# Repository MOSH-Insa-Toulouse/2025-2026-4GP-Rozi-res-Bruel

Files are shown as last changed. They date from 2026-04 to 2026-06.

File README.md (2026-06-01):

# 2025-2026-4CP - Projet de capteur low-tech en graphite - Marilou Rozières & Adélaïs Bruel 

## SOMMAIRE
*** 
  - [I. Contexte et description du projet](#contexte-et-description-du)
  - [II. Livrables](#livrables)
  - [III. Matériel nécessaire](#matériel-nécessaire)
  - [IV. Conditionnement analogique](#conditionnement-analogique)
  - [V. Modélisaiotn et simulation](#modélisaiton-et-simulation)
  - [VI. Conception](#conception)
  - [VII. Fabrication](#fabrication)
  - [VIII. Développement firmware et software](#développement-firmware-et-software)
  - [IX. Analyse et caractérisation](#analyse-et-caractérisation)
  - [X. Datasheet](#datasheet)
  - [XI. Conclusion](#conclusion)

*** 

## Contexte et description du projet 

&nbsp;&nbsp;&nbsp;&nbsp;&nbsp;&nbsp;Ce projet s'inscrit dans le cadre de l'UF "Du capteur au banc de test" de la 4ème année Génie Physique de l'INSA Toulouse. 
L'objectif de ce projet est de concevoir, modéliser, prototyper, caractériser et analyser un capteur de déformation low-tech.

&nbsp;&nbsp;&nbsp;&nbsp;&nbsp;&nbsp;Le principe de fonctionnement du capteur repose sur la piézorésistivité d'un dépôt de graphite (réalisé à l'aide d'un simple crayon de bois) sur un support flexible (une feuille de papier). 
Microscopiquement, le trait de crayon est un agglomérat de feuillets de graphite. Dans ce milieu granulaire complexe, la conduction se fait principalement par effet tunnel : les nombreux grains sont séparés par de très fins interstices, la probabilité de passage des électrons d'un grain de graphite à l'autre par franchissement de l'interstice est non nulle si cette barrière est suffisament fine. Cette probabilité dépend exponentiellement de la distance *d* qui sépare les deux grains.
Ce paramètre physique est alors à l'origine de la variation de résistance : en tension, l'écart *d* entre les particules augmente, la probabilité de passage est plus faible, la résistance globale du capteur augmente. 
Tandis qu'en compression, la distance *d* diminue, les particules se rapprochent, la probabilité d'échange augmente, la résistance chute. 
La dépendance exponentielle de la résistance à la distance *d* explique pourquoi une très faible variation du capteur va nous permettre de lire des varirations de signal (résistance) importantes. 

&nbsp;&nbsp;&nbsp;&nbsp;&nbsp;Pour passer d'un trait de crayon à un capteur fonctionnel, le projet s'est déroulé selon ces différentes phases :
- **Conditionnement analogique** : Conception d'un amplificateur transimpédance (conversion courant-tension) pour transformer les variations de courant (de l'ordre du nA) en un signal de tension exploitable (0−5V).
- **Modélisation et Simulation** : Utilisation de LTSpice pour dimensionner les filtres actifs et passifs afin d'éliminer le bruit parasite (notamment le 50 Hz du secteur).
- **Conception** : Routage d'un circuit imprimé (Shield PCB) sous KiCad pour intégrer l'électronique, l'écran OLED et le module Bluetooth.
- **Fabrication** : Réalisation physique du PCB par insolation, gravure chimique (perchlorure de fer), perçage et soudure des composants.
- **Développement Firmware & Software** : Programmation de la carte Arduino (gestion de l'I2C, SPI et UART) et création d'une interface mobile sous MIT App Inventor.
- **Analyse** : Caractérisation du capteur sur un banc de test dédié et rédaction d'une datasheet technique.

Ce document a pour objectif d'expliciter ces différentes étapes.  

## Livrables 
Les livrables attendus sont les suivants : 
- **Un shield PCB connecté à une carte arduino UNO** avec différents composants : un capteur graphite, un amplificateur transimpédance, un module bluetooth, un écran OLED, un flex sensor commercial, un potentiomètre digital, un encodeur rotatoire. D'autres composants peuvent être implémentés ;
- **Un code arduino** qui gère les différents composants cités précédemments (mesures de contraintes, échanges bluetooth et OLED, potentiomètre digital et boutons) ;
- **Une application Android** (sous MIT App Inventor) interfaçant le PCB et le code Arduino correspondant;
- **Une datasheet du capteur** reprenant toutes ses caractéristiques ainsi que ses tests.

## Matériel nécessaire

Afin de réaliser notre dispositif électronique, nous avons eu besoin de :

**Pour le montage amplificateur transimpédance :**

- Résistances : une de 1 kΩ, une de 10 kΩ et deux de 100 kΩ - une troisième de 100 kΩ peut être prévue, mais peut aussi être substituée par une résistance variable (le potentiomètre digital), choix que l'on a fait ;
- Potentiomètre digital MCP41050 et son support ;
- Amplificateur opérationnel LTC1050 et son support ;
- Capacités : trois de 100 nF et une de 1 μF.

**Pour le reste du dispositif :**

- Arduino Uno et son câble d’alimentation ;
- Résistance : une de 47kΩ pour le flex sensor ;
- Module Bluetooth HC05 ;
- Ecran OLED de dimension 128*64 ;
- Flex sensor ;
- Encodeur rotatoire ;
- Capteur graphite et 2 pinces crocodiles ;
- 20 sockets ;
- 35 headers.

## Conditionnement analogique 

&nbsp;&nbsp;&nbsp;&nbsp;&nbsp;Le capteur en graphite présente une résistance extrêmement élevée (de l'ordre du MΩ), ce qui génère des courants infimes (pico- à nanoampères) sous une tension de 5 V. Pour transformer ce signal en une tension exploitable par l’ADC d'une Arduino UNO (0−5V), nous avons conçu un amplificateur transimpédance, réalisé comme suit : 

Capture d’écran 2026-03-27 à 16 34 57

Nous avons utilisé l’AOP LTC1050 car il possède un courant de biais d'entrée extrêmement faible et un offset quasi nul, évitant ainsi de fausser les mesures de courants très faibles. 
Nous avons placé une résistance de protection (R5) en entrée pour protéger l'AOP contre les décharges électrostatiques, ainsi qu'une résistance du shunt (R1) qui assure la référence à la masse. La résistance de rétroaction (R2) a été subsitué par un potentiomètre digital MCP41050 pour ajuster dynamiquement le gain du montage via le code Arduino. 
Les trois étages de filtrages de cet amplificateur permet de minimiser au maximum les bruits parasites. 

## Modélisation et simulation 

&nbsp;&nbsp;&nbsp;&nbsp;&nbsp;Avant la fabrication, l'ensemble du circuit a été modélisé sous LTSpice pour vérifier que l'amplification convertit bien les nanoampères en une tension comprise entre 0 et 5V. Cette modélisation a également permis de valider l'efficacité de nos trois étage de filtrage :  
- Filtre passe-bas (16 Hz) : élimination des hautes fréquences parasites.
- Filtre passe-bas (1,6 Hz) : atténuation drastique du bruit secteur (50 Hz)
- Filtre passe-bas (1,6 kHz) : supression des interférences liées à la communication de l'ADC.

Schema du montage transimpedance

## Conception 
&nbsp;&nbsp;&nbsp;&nbsp;&nbsp;La phase de conception a été réalisée sur Kicad. L'ojectif était de créer un Shield compatible avec le format de l'Arduino UNO. 
Cela nous demandé trois étapes : 
- Saisie des empreintes et des shématics associés pour nos différents composants : AOP, potentiomètre digital, écran OLED, encodeur rotatoire et module bluetooth. 
- Le routage du PCB : optimisation du placement des composants pour réduire les longueurs de pistes et visualisation 3D des composants pour vérifier l'abscence de conflits mécaniques entre tous les composants.
- Ajout d'un plan de masse pour minimiser le bruit électromagnétique et stabiliser les mesures de hautes impédances.
pcb sch

## Fabrication 
&nbsp;&nbsp;&nbsp;&nbsp;&nbsp;La réalisation du prototype a été faite par ce processus de fabrication : 
- Insolation & gravure (réalisé par Catherine Crouzet) : transfert du masque de gravure sur une plaque époxy et passage au perchlorure de fer.
- Nettoyage (réalisé par Catherine Crouzet) : Retrait de la résine photosensible à l'acétone pour révéler les pistes de cuivre.
- Percage & soudure : montage manuel des composants sur le PCB final.
- Assemblage : soudure des composants.



## Développement Firmaware et Software 

Le système est piloté par deux pôles : 
- Firmware (Arduino) : utilisation des bibliothèques *Adafruit_SSD1306* (OLED), *SPI* (potentiomètre) et *SoftwareSerial* (Bluetooth). Le code génère un menu intéractif via l'encodeur rotatoire pour calibrer le capteur et lancer les mesures.
- Interface mobile : développement d'une application Android sur MIT App Inventor qui communique en Bluetooth pour afficher la résistance en temps réel et tracer la courbe de déformation directement sur le smartphone.




## Analyse et caractérisation

**Dispositif de mesure :** 

&nbsp;&nbsp;&nbsp;&nbsp;&nbsp;Afin d’obtenir les caractéristiques spécifiques du capteur, nous avons utilisé un banc de test composé de six cylindres de diamètre différent, permettant d’étudier la résistance de notre capteur en tension et en compression pour six valeurs de contraintes connues.  
sch

&nbsp;&nbsp;&nbsp;&nbsp;&nbsp;Nous avons choisi d’étudier trois types de crayons à papier différent : le B, le 3B et le 6B. Nous avons donc conçu trois capteurs différents, et avons déterminé pour chacun d’entre eux douze valeurs : six en compression et six en tension. Ces mesures nous ont permises d’établir la variation relative de résistance en fonction de la déformation grâce aux formules suivantes : 

Calcul de la déformation ∶ ε=  e/D

Avec e l’épaisseur du papier utilisé pour le capteur et D le diamètre du cylindre sur lequel est effectué la mesure. 

Calcul de la variation relative de résistance∶ ∆R/R0 (%)=  (R_mesuré-R0)/R0

**Résultats des mesures :**

En tension, nous obtenons alors la variation relative de résistance en fonction de la déformation suivante : 
sch

En compression, nous obtenons la variation relative de la résistance en fonction de la déformation suivante : 

sch

&nbsp;&nbsp;&nbsp;&nbsp;&nbsp;Les allures des courbes sont pertinentes : les crayons à papier sont constitués de graphite et d’un liant isolant (argile). Afin de comprendre la différence entre les différents types de crayons (B, 3B, 6B, …) il faut se pencher sur le seuil de percolation de ceux-ci. Le seuil de percolation représente la fraction volumique nécessaire de charge conductrice (ici le graphite) afin que celles-ci forment un réseau continu interconnecté à travers la matrice isolante (l’argile). A partir de ce seuil de matière conductrice, les propriétés macroscopiques du matériau basculent d’un comportement isolant à un comportement conducteur. Un crayon 6B est saturé en graphite et contient très peu d’argile (seuil de percolation largement dépassé), il représente alors un milieu très conducteur. Quand une déformation est appliquée au capteur, des micro fissures sont créées, mais il existe une multitude de chemins secondaires conducteurs, la résistance globale du capteur n’est que très peu impactée. A contrario, le crayon B a une mine dure, il contient une forte proportion d’argile (très proche du seuil de percolation), les grains de graphite sont plus dispersés dans la matrice d’argile isolante, lorsqu’une déformation est appliquée, les rares chemins électriques entre les grains de graphite se brise très facilement, la résistance varie alors fortement. 

**Analyse :**

&nbsp;&nbsp;&nbsp;&nbsp;&nbsp;La sensibilité (facteur de jauge k) est définie par : k=  (∆R/R0)/ε
Le crayon B possède la meilleure sensibilité puisque pour une déformation donnée il génère une plus grande variation de résistance. Diminuer la concentration de charge conductrice (en passant de 6B à B) augmente alors fortement la piézorésistivité du matériau. 
Pour conclure, pour une application requérant une grande sensibilité un capteur réalisé avec un crayon de type B est le mieux, néanmoins celui-ci aura tendance à « s’user » plus vite puisque que sa composition est au niveau du seuil de percolation. Tandis que pour une application nécessitant moins de précision mais plus de robustesse, un crayon très gras tel que le 6B conviendra mieux, puisque qu’étant très loin du seuil de percolation il peut être déformé plus de fois avant de ne plus avoir chemins conducteurs possible entre les particules.  

## Datasheet
La datasheet du capteur est disponible [ici](https://github.com/MOSH-Insa-Toulouse/2025-2026-4GP-Rozi-res-Bruel/blob/main/DATASHEET/DATASHEET.pdf)

## Conclusion 
&nbsp;&nbsp;&nbsp;&nbsp;&nbsp;Pour conclure ce projet, ce capteur low tech est adapté non pas à la lecture d’une valeur de résistance et donc de déformation mais plutôt à la détection d’un mouvement. Il serait également intéressant dans une application jetable puisque qu’au bout de 5/10 utilisations il n’est plus fonctionnel.

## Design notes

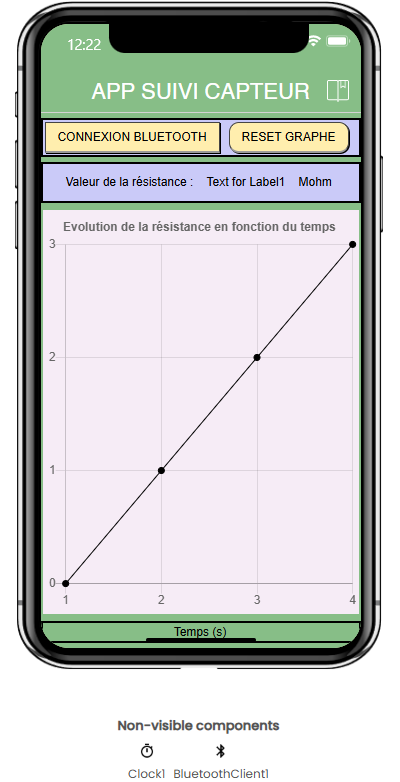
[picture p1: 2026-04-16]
APPLICATION_ANDROID/face_avant_app.png

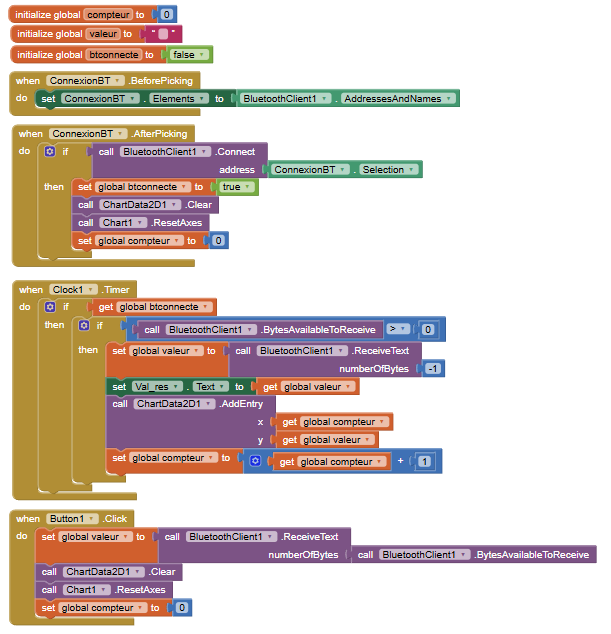
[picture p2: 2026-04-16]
APPLICATION_ANDROID/face_arriere_app.png

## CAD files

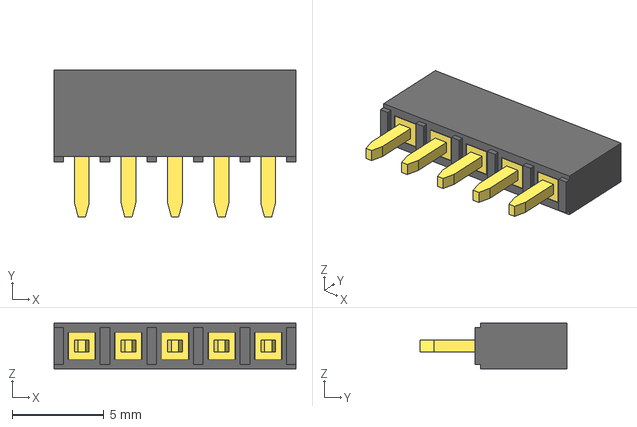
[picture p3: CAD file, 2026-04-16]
KICAD/Models 3D/5-Pin Header - Female - 2.54mm.step
13.2 x 8.00 x 2.50 mm

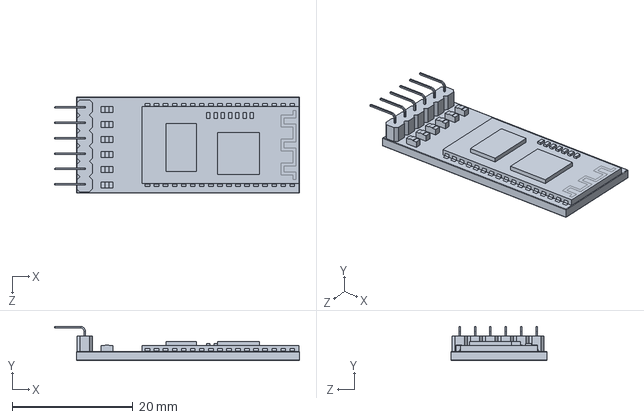
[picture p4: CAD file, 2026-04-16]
KICAD/Models 3D/HC05_BLUETOOTH.STEP
40.6 x 5.67 x 16.0 mm

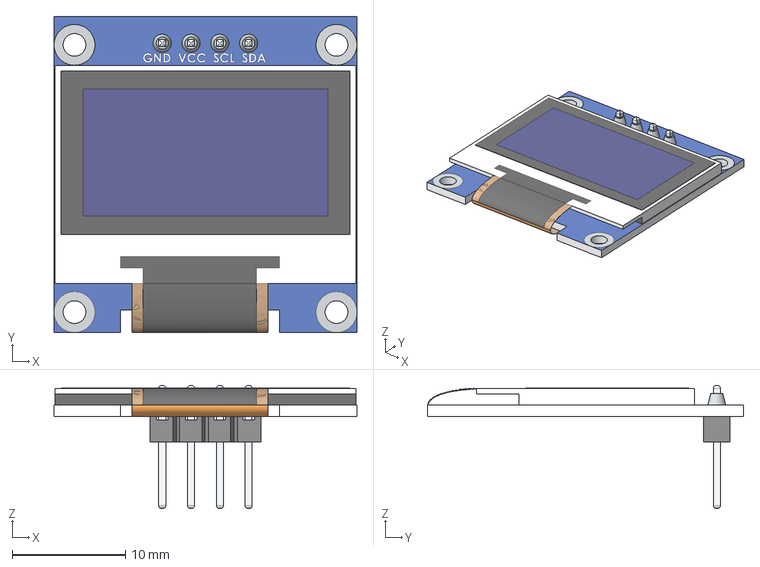
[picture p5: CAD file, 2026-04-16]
KICAD/Models 3D/OLED-128x64-0.96.step
26.7 x 27.9 x 10.8 mm

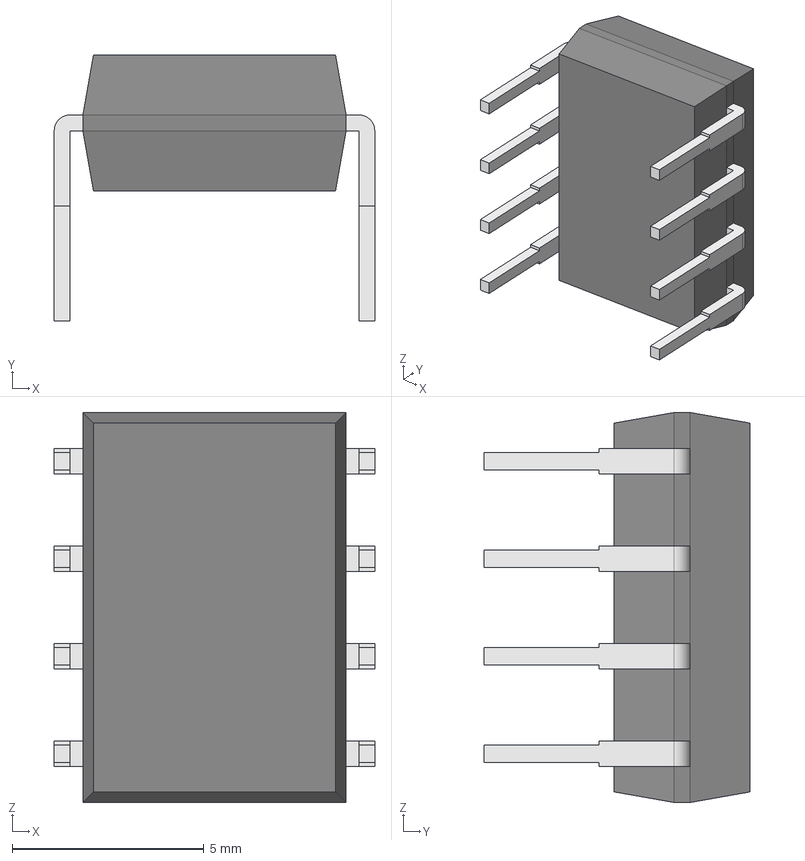
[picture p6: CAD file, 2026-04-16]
KICAD/Models 3D/LTC1050CN8_PBF.step
8.35 x 6.93 x 10.2 mm
Body001 (Mirror #1) x 5

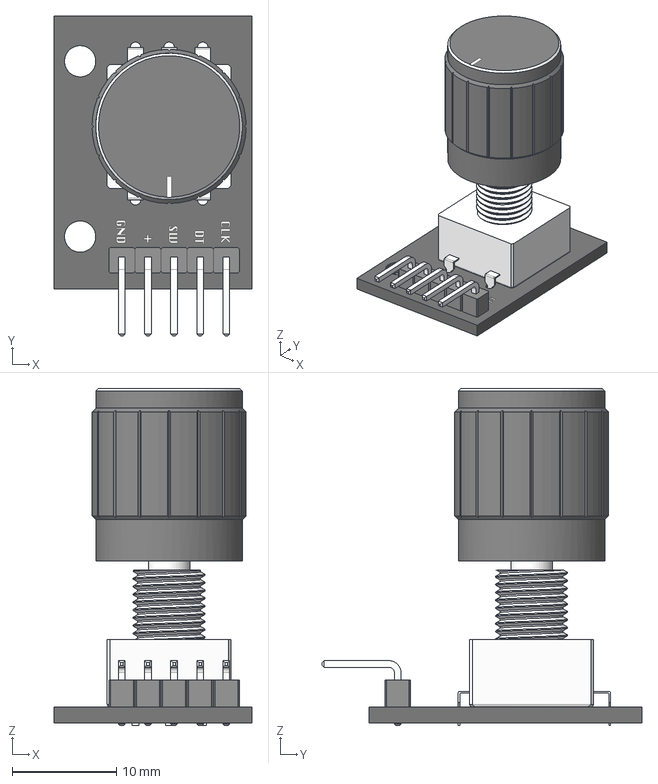
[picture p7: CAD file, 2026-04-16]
KICAD/Models 3D/Rotary Encoder - KY-040.step
19.0 x 30.8 x 32.4 mm

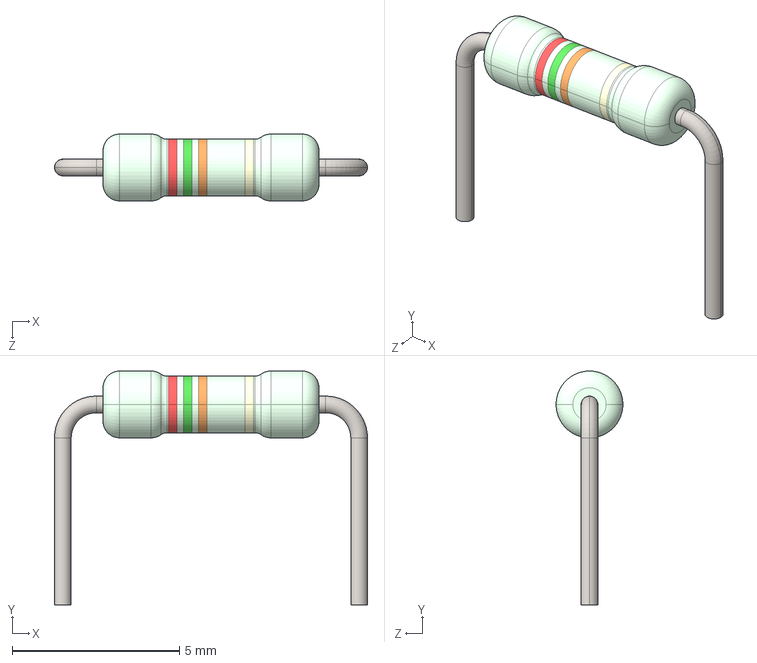
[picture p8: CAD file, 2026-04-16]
KICAD/Models 3D/Resistor.STEP
9.36 x 7.00 x 2.00 mm

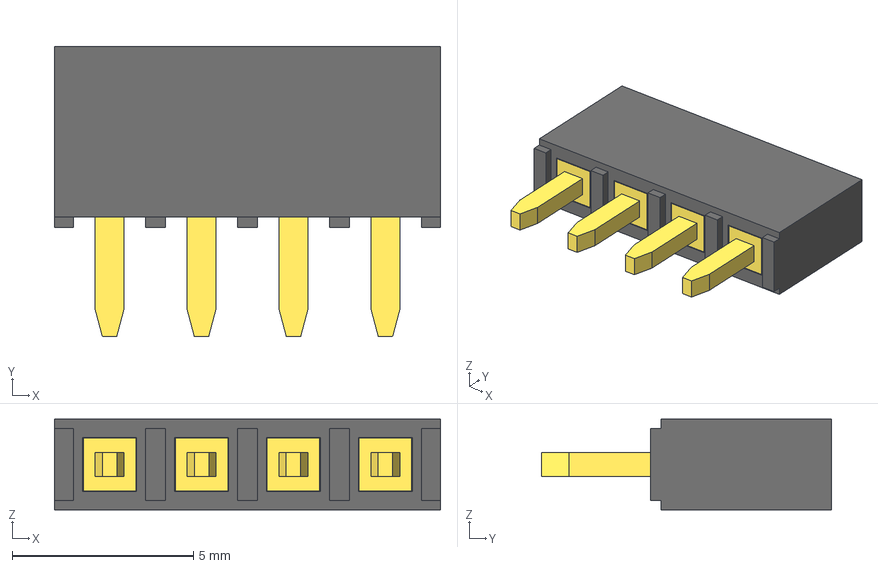
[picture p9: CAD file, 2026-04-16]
KICAD/Models 3D/4-Pin Header - Female - 2.54mm.step
10.7 x 8.00 x 2.50 mm

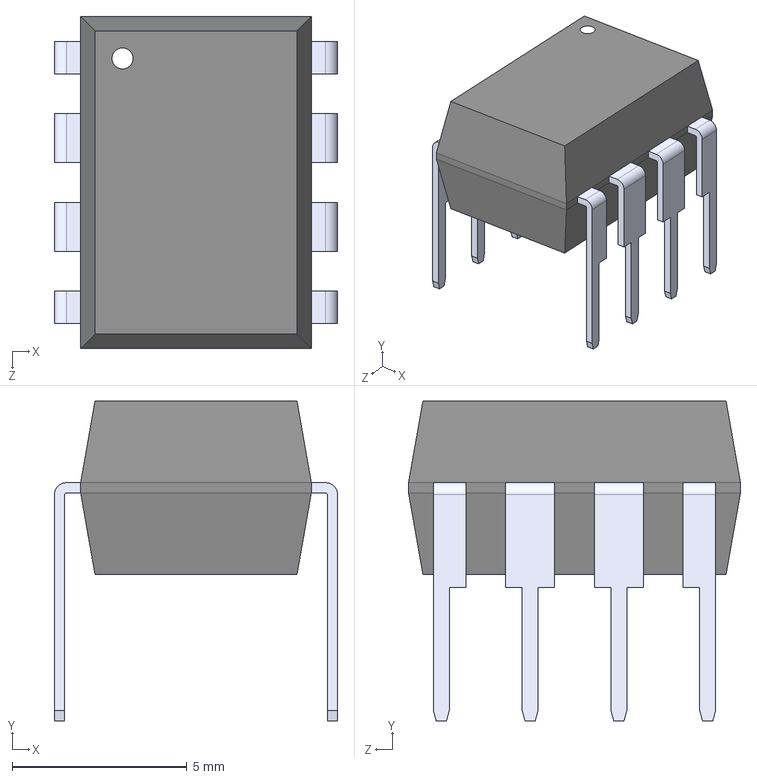
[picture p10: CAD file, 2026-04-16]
KICAD/Models 3D/MCP41010-E_P.step
8.10 x 9.14 x 9.50 mm

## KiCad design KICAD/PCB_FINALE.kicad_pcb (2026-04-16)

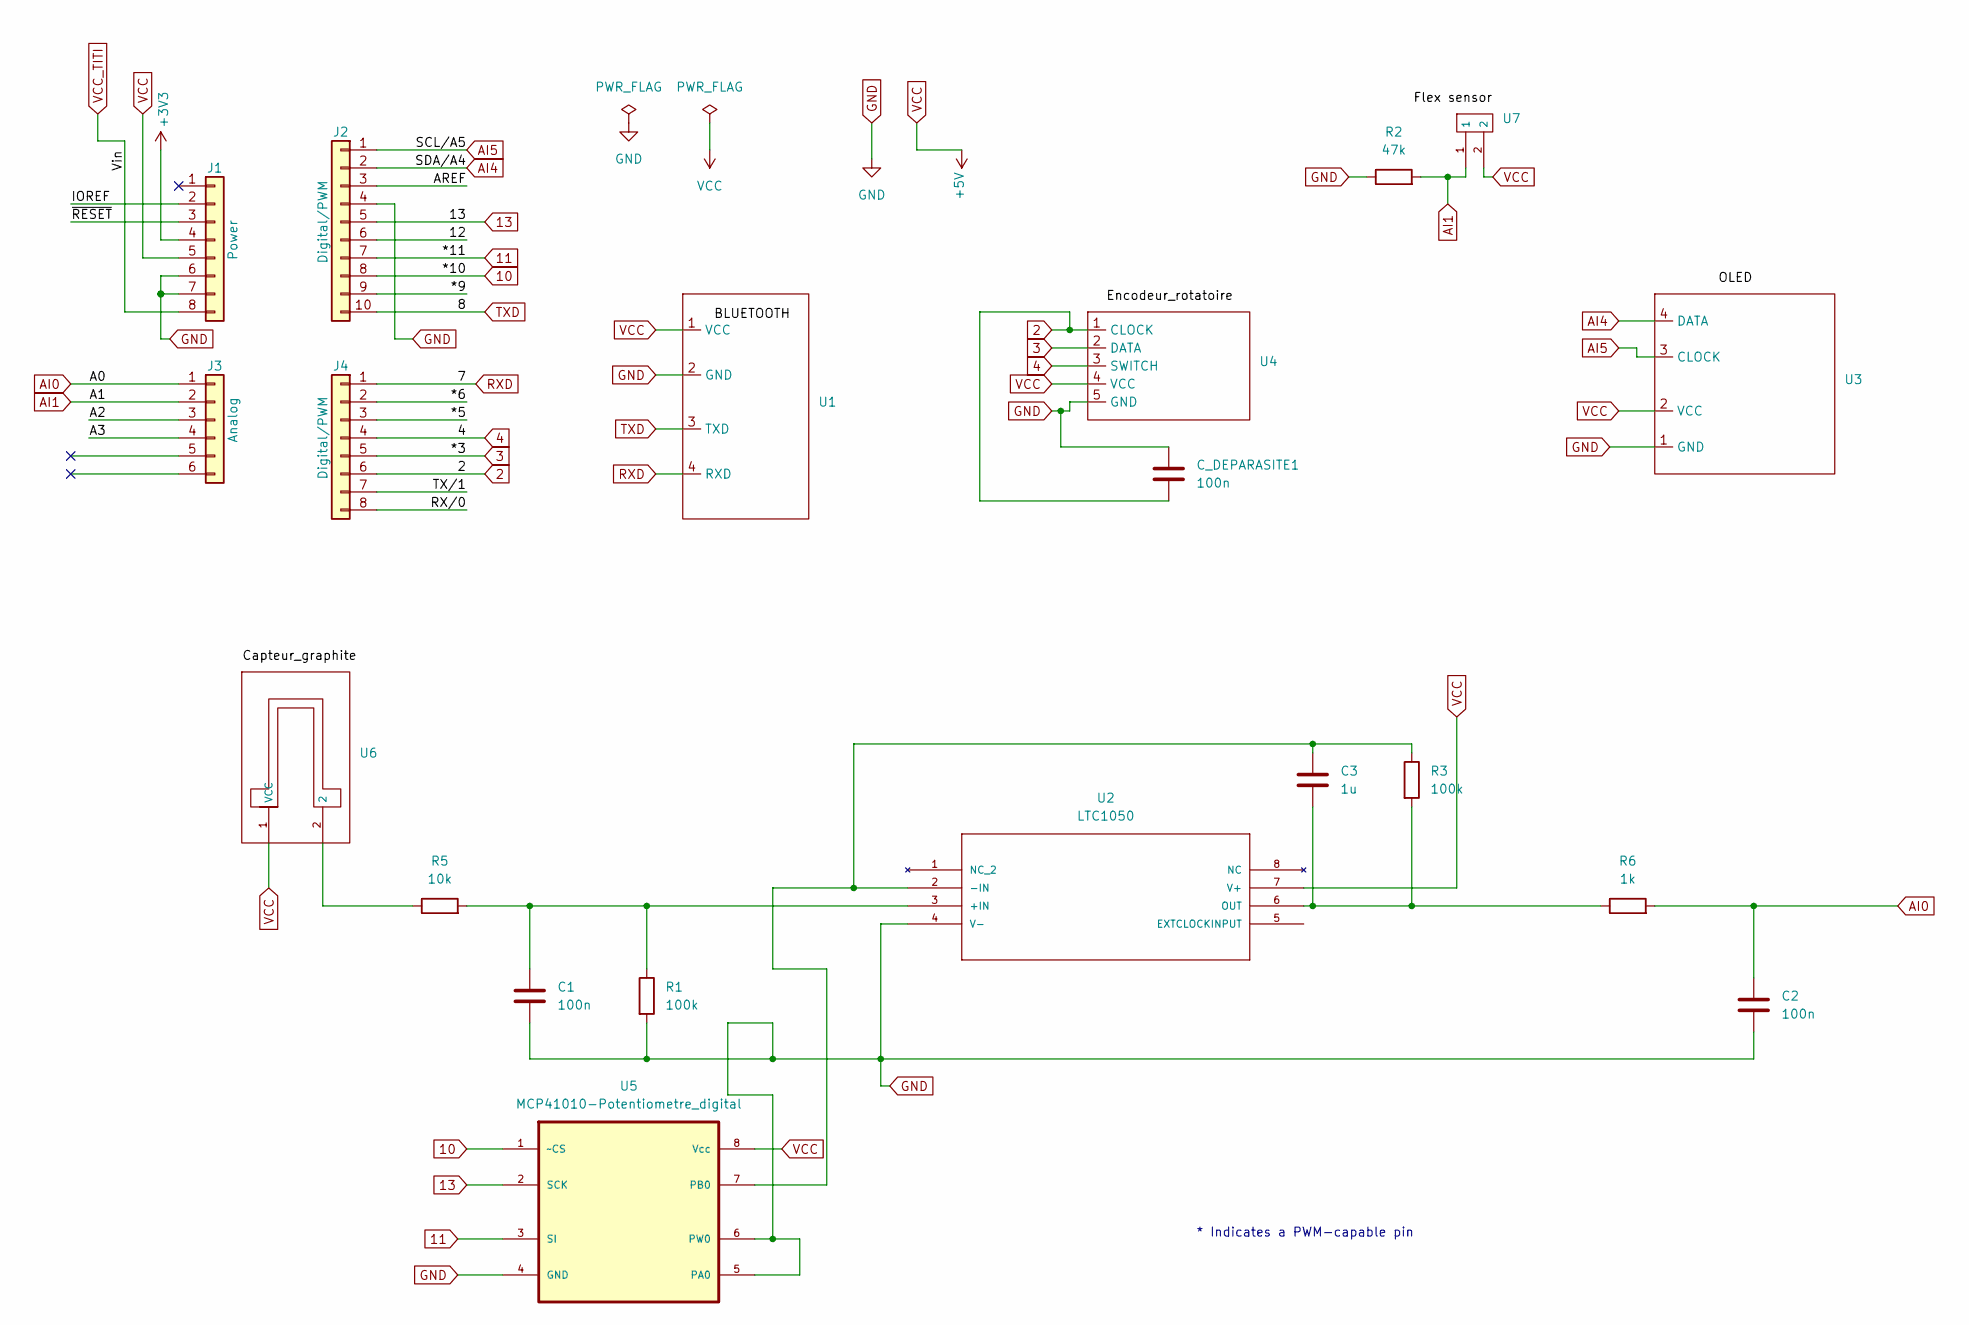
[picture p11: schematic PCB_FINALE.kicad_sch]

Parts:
C1, C2: 100n; CapaOk
C3: 1u; CapaOk
C_DEPARASITE1: 100n; CapaOk
J1: Power; PinSocket_1x08_P2.54mm_Vertical
J2: Digital/PWM; PinSocket_1x10_P2.54mm_Vertical
J3: Analog; PinSocket_1x06_P2.54mm_Vertical
J4: Digital/PWM; PinSocket_1x08_P2.54mm_Vertical
R1, R3: 100k; RES5
R2: 47k; RES5
R5: 10k; RES5
R6: 1k; RES5
U1: Bluetouth_HC05
U2: LTC1050; PDIP-8_N; MANUFACTURER_PART_NUMBER ltc1050cn8
U3: OLED_EMPREINTE
U4: ENCODEUR_ROTATOIRE
U5: MCP41010-Potentiometre_digital; Potentiomètre_digital
U6: capteur_graphite
U7: FLEX_SENSOR

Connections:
2: C_DEPARASITE1.2, J4.6, U4.1 (CLOCK)
3: J4.5, U4.2 (DATA)
4: J4.4, U4.3 (SWITCH)
10: J2.8, U5.1 (~CS)
11: J2.7, U5.3 (SI)
13: J2.5, U5.2 (SCK)
+3V3: J1.4
/12: J2.6
/*5: J4.3
/*6: J4.2
/*9: J2.9
/A2: J3.3
/A3: J3.4
/AREF: J2.3
/IOREF: J1.2
/RX/0: J4.8
/TX/1: J4.7
/~RESET: J1.3
AI0: C2.1, J3.1, R6.2
AI1: J3.2, R2.2, U7.1
AI4: J2.2, U3.4 (DATA)
AI5: J2.1, U3.3 (CLOCK)
GND: C1.2, C2.2, C_DEPARASITE1.1, J1.6, J1.7, J2.4, R1.2, R2.1, U1.2 (GND), U2.4 (V-), U3.1 (GND), U4.5 (GND), U5.4 (GND), U5.5 (PA0), U5.6 (PW0)
unnamed: R5.1, U6.2
unnamed: C1.1, R1.1, R5.2, U2.3 (+IN)
unnamed: C3.1, R3.1, U2.2 (-IN), U5.7 (PB0)
unnamed: C3.2, R3.2, R6.1, U2.6 (OUT)
RXD: J4.1, U1.4 (RXD)
TXD: J2.10, U1.3 (TXD)
VCC: J1.5, U1.1 (VCC), U2.7 (V+), U3.2 (VCC), U4.4 (VCC), U5.8 (Vcc), U6.1 (VCC), U7.2
VCC_TITI: J1.8

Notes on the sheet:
* Indicates a PWM-capable pin

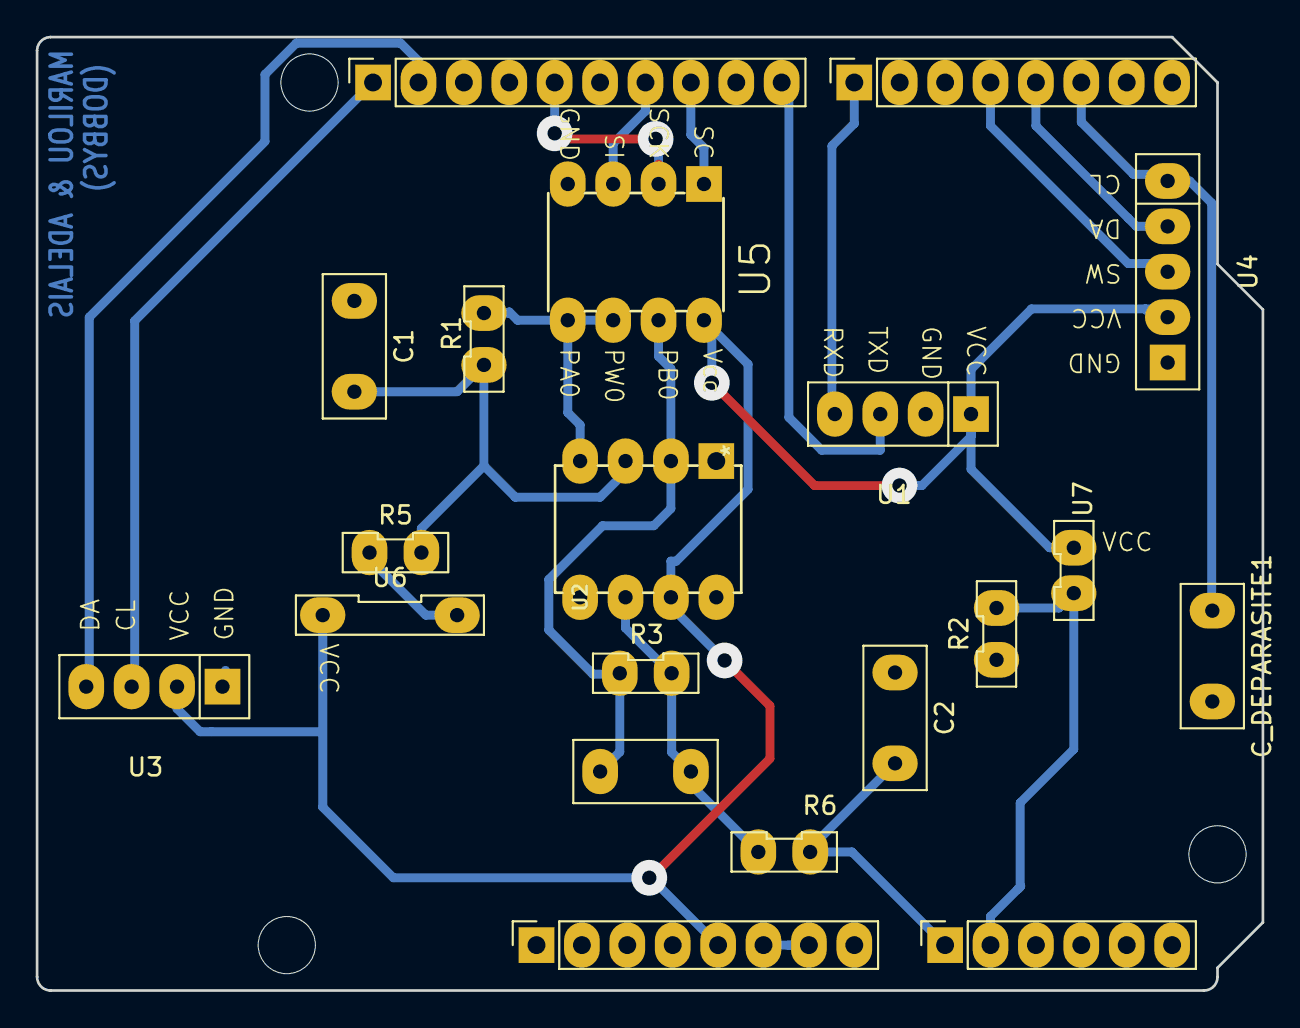
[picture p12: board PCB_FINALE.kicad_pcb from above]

Board: 2 copper layers, 68.6 x 53.3 mm, 23 parts (0 on the bottom side), 18 nets.

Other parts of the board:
MH1, MH2, MH4: MountingHole_3.2mm

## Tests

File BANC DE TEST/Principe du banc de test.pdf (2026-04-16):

### Banc de test et résultats

I – Dispositif de mesure
II – Résultats des mesures III – Conclusion

## I – Dispositif de mesure

Afin d’obtenir les caractéristiques spécifiques du capteur, nous avons utilisé un banc de test composé de six cylindres de diamètre différent, permettant d’étudier la résistance de notre capteur en tension et en compression pour six valeurs de contraintes connues.

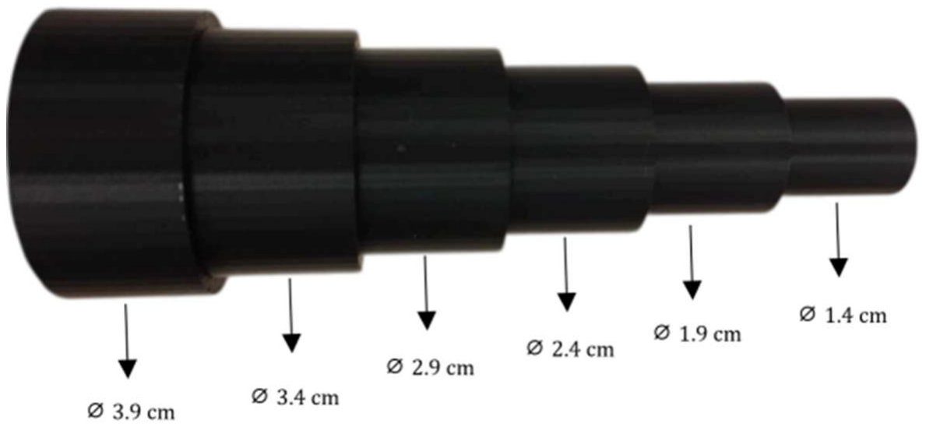
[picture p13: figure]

Figure 1 : Banc de test imprimé en 3D
Nous avons choisi d’étudier trios types de crayons à papier différent : le B, le 3B et le 6B. Nous avons donc conçu trois capteurs différents, et avons déterminé pour chacun d’entre eux douze valeurs : six en compression et six en tension. Ces mesures nous ont permises d’établir la variation relative de résistance en fonction de la déformation grâce aux formules suivantes :
o Calcul de la déformation ∶ | ε =

Avec e l’épaisseur du papier utilisé pour le capteur et D le diamètre du cylindre sur lequel est effectué la mesure.

o Calcul de la variation relative de résistance ∶

∆R
R0
| (%) = Ré − R0
R0

## II – Résultats des mesures

Nous avons organisé nos résultats dans les tableaux suivants :

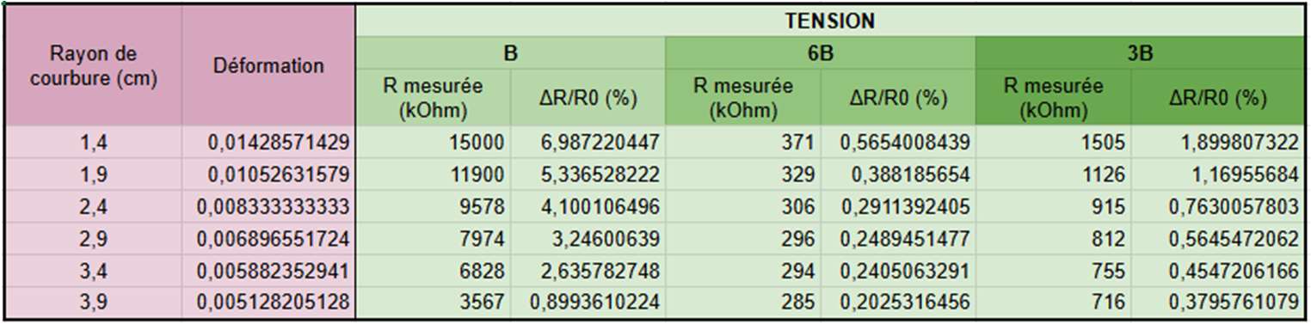
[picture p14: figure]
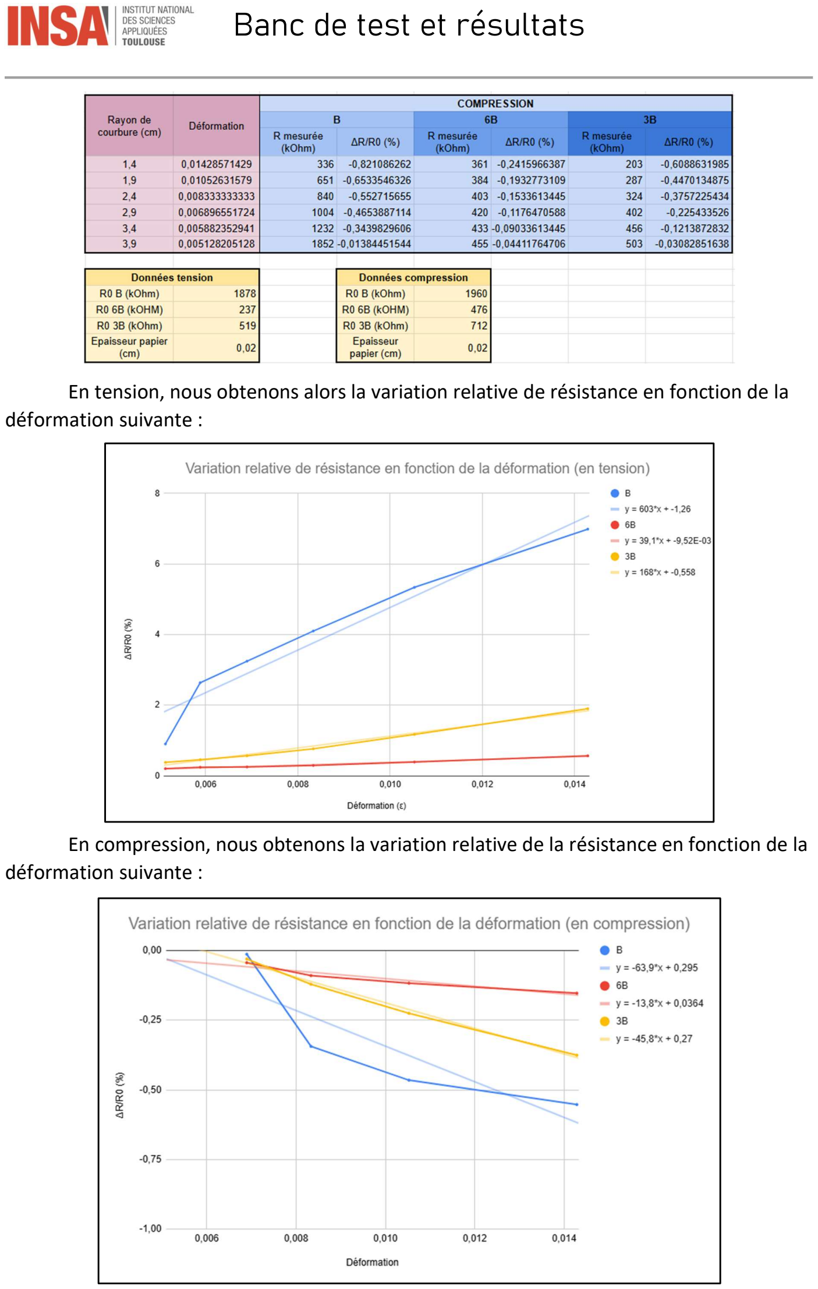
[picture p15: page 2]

En tension, nous obtenons alors la variation relative de résistance en fonction de la déformation suivante :

En compression, nous obtenons la variation relative de la résistance en fonction de la déformation suivante :

Les allures des courbes sont pertinentes : les crayons à papier sont constitués de graphite et d’un liant isolant (argile). Afin de comprendre la différence entre les différents types de crayons (B, 3B, 6B, …) il faut se pencher sur le seuil de percolation de ceux-ci. Le seuil de percolation représente la fraction volumique nécessaire de charge conductrice (ici le graphite) afin que celles-ci forment un réseau continu interconnecté à travers la matrice isolante (l’argile). A partir de ce seuil de matière conductrice, les propriétés macroscopiques du matériau basculent d’un comportement isolant à un comportement conducteur. Un crayon 6B est saturé en graphite et contient très peu d’argile (seuil de percolation largement dépassé), il représente alors un milieu très conducteur. Quand une déformation est appliquée au capteur, des micro fissures sont créées, mais il existe une multitude de chemins secondaires conducteurs, la résistance globale du capteur n’est que très peu impactée. A contrario, le crayon B a une mine dure, il contient une forte proportion d’argile (très proche du seuil de percolation), les grains de graphite sont plus dispersés dans la matrice d’argile isolante, lorsqu’une déformation est appliquée, les rares chemins électriques entre les grains de graphite se brise très facilement, la résistance varie alors fortement.

## III – Conclusion

La sensibilité (facteur de jauge k) est définie par :

k =

∆R/R0
ε
Le crayon B possède la meilleure sensibilité puisque pour une déformation donnée il génère une plus grande variation de résistance. Diminuer la concentration de charge conductrice (en passant de 6B à B) augmente alors fortement la piézorésistivité du matériau.
Pour conclure, pour une application requérant une grande sensibilité un capteur réalisé avec un crayon de type B est le mieux, néanmoins celui-ci aura tendance à « s’user » plus vite puisque que sa composition est au niveau du seuil de percolation. Tandis que pour une application nécessitant moins de précision mais plus de robustesse, un crayon très gras tel que le 6B conviendra mieux, puisque qu’étant très loin du seuil de percolation il peut être déformé plus de fois avant de ne plus avoir chemins conducteurs possible entre les particules.

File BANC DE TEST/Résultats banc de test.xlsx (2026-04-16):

Diamètre (cm) | Déformation | TENSION
 |  | B |  | 6B |  | 3B |  | FLEX SENSOR
 |  | R mesurée (kOhm) | ΔR/R0 | R mesurée (kOhm) | ΔR/R0 (%) | R mesurée (kOhm) | ΔR/R0 | R mesurée (kOhm) | ΔR/R0
1.4 | 0.01428571429 | 15000 | 6.987220447 | 371 | 0.5654008439 | 1505 | 1.899807322
1.9 | 0.01052631579 | 11900 | 5.336528222 | 329 | 0.388185654 | 1126 | 1.16955684
2.4 | 0.008333333333 | 9578 | 4.100106496 | 306 | 0.2911392405 | 915 | 0.7630057803
2.9 | 0.006896551724 | 7974 | 3.24600639 | 296 | 0.2489451477 | 812 | 0.5645472062 | 78 | 2.545454545
3.4 | 0.005882352941 | 6828 | 2.635782748 | 294 | 0.2405063291 | 755 | 0.4547206166 | 75 | 2.409090909
3.9 | 0.005128205128 | 3567 | 0.8993610224 | 285 | 0.2025316456 | 716 | 0.3795761079 | 68 | 2.090909091
Diamètre (cm) | Déformation | COMPRESSION
 |  | B |  | 6B |  | 3B
 |  | R mesurée (kOhm) | ΔR/R0 | R mesurée (kOhm) | ΔR/R0 | R mesurée (kOhm) | ΔR/R0
1.4 | 0.01428571429 | 129 | -0.9313099042 | 361 | -0.2415966387 | 203 | -0.6088631985
1.9 | 0.01052631579 | 324 | -0.8274760383 | 384 | -0.1932773109 | 287 | -0.4470134875
2.4 | 0.008333333333 | 418 | -0.7774227902 | 403 | -0.1533613445 | 324 | -0.3757225434
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

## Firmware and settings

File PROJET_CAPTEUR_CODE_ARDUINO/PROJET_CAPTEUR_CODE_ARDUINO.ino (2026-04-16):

//BIBLIOTHEQUES

#include <SoftwareSerial.h>  //Bluetooth
#include <Wire.h>   //OLED
#include <Adafruit_SSD1306.h>   //OLED
#include <SPI.h>  //Potentiomètre
#include <stdlib.h>

//DEF & CST
#define baudrate 9600

  //Bluetooth:
#define rxPin 8
#define txPin 7

  //Encodeur rotatoire:
#define Encodclkpin 2 
#define Encoddtpin 3 
#define Encodswpin 4

  //OLED:
#define nombreDePixelsEnLargeur 128 
#define nombreDePixelsEnHauteur 64 
#define brocheResetOLED -1 
#define adresseI2CecranOLED 0x3C
#define nb_item 3 //Nombre de choix dans le menu

  //Potentiomètre digital:
#define MCP_NOP                 0b00000000
#define MCP_WRITE               0b00010001
#define MCP_SHTDWN              0b00100001

  //Flex sensor:
#define flexPin A1

  //Capteur graphite:
#define graphitePin A0

//VARIABLES

  //Bluetooth:
SoftwareSerial mySerial (rxPin, txPin);

  //Encodeur:
volatile int Pas_encod = 0; // variable pour stocker la lecture de l'etat du bouton (crans)
int etat_bouton = 0; // variable pour stocker la lecture de l'etat du bouton (enfoncé)
int Menu = 0;

  //Flex sensor:
float val_flexs = 0;
float Vflexs, Rflexs = 0.0;
const float VCC = 5.0;
const float Rdiv = 47000.0;
const float flatres = 24700.0;
const float bentres = 80000.0;

  //Capteur graphite:
unsigned long previousMillis = 0; //Pour faire une clock
int val_graph = 0;
float VGraph, RGraph = 0.0;
const float R1 = 100000;
const float R3 = 100000;
const float R5 = 10000;

  //OLED:
int choix = 0;
float lastval = -100.0;

  //Potentiomètre digital:
const int csPin = 10;
const int maxPositions = 256;
const long rAB = 47000;
const byte rWiper = 125;
const byte pot0 = 0x11;
const byte pot0shutdown = 0x21;
float R2;

Adafruit_SSD1306 ecranOLED (nombreDePixelsEnLargeur, nombreDePixelsEnHauteur, &Wire, brocheResetOLED);

void setup() { //Configuration et initialisation des différents composants 

  Serial.begin(9600);

  //OLED:
  if (!ecranOLED.begin (SSD1306_SWITCHCAPVCC, adresseI2CecranOLED)) { // Arrêt du programme (boucle infinie) si échec d'initialisation
    while(1);
  }

  //Calibration
  ecranOLED.clearDisplay();
  ecranOLED.setTextSize(1);
  ecranOLED.setTextColor(SSD1306_WHITE);
  ecranOLED.setCursor(0,0);
  ecranOLED.println(F("Calibration en cours..."));
  ecranOLED.println(F("Veuillez ne pas toucher"));
  ecranOLED.println(F("le capteur."));
  ecranOLED.display();

  //Pontentiometre digital :
  pinMode(csPin, OUTPUT);
  digitalWrite(csPin, HIGH);
  SPI.begin();
  Calibration(); 
  ecranOLED.clearDisplay();
  ecranOLED.setCursor(0,0);
  ecranOLED.println(F("Calibration OK !"));
  ecranOLED.display();
  delay(1000);

  //Encodeur rotatoire:
  pinMode(Encodclkpin, INPUT); 
  digitalWrite(Encodclkpin, HIGH); 
  pinMode(Encoddtpin, INPUT); 
  digitalWrite(Encoddtpin, HIGH);
  pinMode(Encodswpin, INPUT); 
  digitalWrite(Encodswpin, HIGH);
  attachInterrupt(0, doEncoder, RISING); // On met une interruption sur l'encodeur

  //Module Bluetooth:
  pinMode (rxPin,INPUT);
  pinMode (txPin,OUTPUT);
  mySerial.begin(baudrate);

  //Capteurs:
  pinMode(flexPin, INPUT);
  pinMode(graphitePin, INPUT);

  delay(500);

}

//LOOP

void loop() {                               // Boucle en continue 

  Afficher_Menu(); //Appelée toutes les 500ms

}

//FONCTIONS

float flexSensor(){                       // Renvoie la valeur de la résistance aux bornes du flex sensor
  float ADCflex = analogRead(flexPin);
  Vflexs = ADCflex * VCC / 1024.0;
  Rflexs = Rdiv * (VCC / Vflexs - 1.0);
  return Rflexs;
}

float graphiteSensor(){                   // Renvoie la valeur de la résisatnce aux bornes du capteur graphite
  float ADCgraph = analogRead(graphitePin); 
  float VGraph = ADCgraph * VCC / 1024.0;
  RGraph = Rdiv*(VCC/VGraph-1.0); 
  return RGraph;
}

float graphiteSensor_voltage(){           // Renvoie la valeur de la tension aux bornes du capteur graphite
  float ADCgraph = analogRead(graphitePin); 
  float VGraph = ADCgraph * VCC / 1024.0; 
  return VGraph;
}

void setPotWiper(int addr, int pas){     // Règle la résistance de sortie du potentiomètre digital
  pas = constrain(pas, 0, 255);
  digitalWrite(csPin, LOW);
  SPI.transfer(addr);
  SPI.transfer(pas);
  digitalWrite(csPin, HIGH);
  R2 = ((rAB * pas) / maxPositions) + rWiper;
}


void Calibration(){                     // Calibre le potentiomètre digital pour avoir une tensoin de 3V avec une tolérance de 0.2V
  float target = 3.0, tol = 0.2;
  int pas = 0;
  char chaine[10];

  do {
    setPotWiper(pot0, pas);
    pas += 5;
    delay(200);
  } while ((graphiteSensor_voltage() < (target - tol) || graphiteSensor_voltage() > (target + tol)) && pas <= 265);
  
  dtostrf(pas, sizeof(chaine)-1, 2, chaine);
  
  if (pas < 265) {
    Serial.println(F("Potentiometer calibrated at pasition : "));
    Serial.print(chaine);

    float val = graphiteSensor();
    dtostrf(val, sizeof(chaine)-1, 2, chaine);
    Serial.println(F("Value : "));
    Serial.print(chaine);
  }
  else {
    Serial.println(F("Potentiometer not calibrated at target 3V"));
  }
} 


void doEncoder(){                          // Lit la position de l'encodeur (lors de l'interruption)
  if ( (digitalRead(Encodclkpin)==HIGH) && (digitalRead(Encoddtpin)==HIGH) ) { 
    Pas_encod++;
  } 
  else if ( (digitalRead(Encodclkpin)==HIGH) && (digitalRead(Encoddtpin)==LOW) ) {  
    Pas_encod--;
  }   
}


void appui_bouton(){                      // Vérifie l'état du bouton de l'endodeur rotatoire (enfoncé ou non)
  etat_bouton = digitalRead(Encodswpin);
  if (etat_bouton == 0) {
    if (Menu == 0) {
      Menu++;
    }
    else {
      Menu--;
    }
  }
}


void Afficher_Liste_Menu(int selection){   //Affiche la liste des menus avec la surbrillance sur le bon titre, gère l'affichage sur le OLED

  ecranOLED.clearDisplay();   
  ecranOLED.setTextSize(2);   
  ecranOLED.setCursor(0, 0);
  ecranOLED.setTextColor (SSD1306_WHITE, SSD1306_BLACK);  
  ecranOLED.println (F("-MENU-"));
  ecranOLED.setTextSize(1);

  if (selection==0){
    ecranOLED.setTextColor(SSD1306_BLACK, SSD1306_WHITE);
    ecranOLED.println(F("Flex Sensor"));
    ecranOLED.setTextColor(SSD1306_WHITE, SSD1306_BLACK);
    ecranOLED.println(F("Graphite Sensor"));
    ecranOLED.setTextColor(SSD1306_WHITE, SSD1306_BLACK);
    ecranOLED.println(F("Calibrer"));
  }
  else if (selection==1){
    ecranOLED.setTextColor(SSD1306_WHITE, SSD1306_BLACK);
    ecranOLED.println(F("Flex Sensor"));
    ecranOLED.setTextColor(SSD1306_BLACK, SSD1306_WHITE);
    ecranOLED.println(F("Graphite Sensor"));
    ecranOLED.setTextColor(SSD1306_WHITE, SSD1306_BLACK);
    ecranOLED.println(F("Calibrer"));
  }
  else if (selection==2){
        ecranOLED.setTextColor(SSD1306_WHITE, SSD1306_BLACK);
    ecranOLED.println(F("Flex Sensor"));
    ecranOLED.setTextColor(SSD1306_WHITE, SSD1306_BLACK);
    ecranOLED.println(F("Graphite Sensor"));
    ecranOLED.setTextColor(SSD1306_BLACK, SSD1306_WHITE);
    ecranOLED.println(F("Calibrer"));

  }
  
  ecranOLED.display();
}


void Ecran_Flex(){                              //Affiche le menu du flex sensor 

  float val = flexSensor();
  char res[20];
  dtostrf (val, 1, 2, res);
  ecranOLED.clearDisplay();
  ecranOLED.setCursor(1, 0);
  ecranOLED.setTextColor (SSD1306_WHITE, SSD1306_BLACK);
  ecranOLED.setTextSize(2);
  ecranOLED.println(F("-Menu1-"));
  ecranOLED.setTextSize(1);
  ecranOLED.println (F("FlexSensor :"));
  ecranOLED.println(F("Resistance (Ohm):"));
  ecranOLED.println(res);
  ecranOLED.display();
}


void Ecran_Graphite(){                        //Affiche le menu du graphite sensor et envoie bluetooth
  float val = graphiteSensor();
  char res[20];
  dtostrf(val, 1, 2, res);
  ecranOLED.clearDisplay();
  ecranOLED.setCursor(1, 0);
  ecranOLED.setTextColor (SSD1306_WHITE, SSD1306_BLACK);
  ecranOLED.setTextSize(2);
  ecranOLED.println(F("-Menu2-"));
  ecranOLED.setTextSize(1);
  ecranOLED.println (F("GraphiteSensor :"));
  ecranOLED.println(F("Resistance (Ohm):"));
  ecranOLED.println(res);
  ecranOLED.display();
  mySerial.println(res);
}


void Afficher_Menu (){                       // Affiche les menus sur l'écran OLED
  unsigned long currentMillis = millis ();  // Sauvegarde la valeur du temps écoulé depuis le lancement du programme

  if (currentMillis - previousMillis >= 500){

    previousMillis = currentMillis;
    appui_bouton();
    choix = abs(Pas_encod) % nb_item;

    switch (abs(choix)){
      case 0 :
        if (Menu == 0) {
          Afficher_Liste_Menu(0);
        }
        else if (Menu == 1) {
          Ecran_Flex();
        }
        break;

      case 1:
        if (Menu == 0) {
          Afficher_Liste_Menu(1);
        }
        else if (Menu == 1) {
          Ecran_Graphite();
        }
        break;
      
      case 2 : 
        if (Menu == 0) {
          Afficher_Liste_Menu(2);
        }
        else if (Menu == 1) {
          ecranOLED.clearDisplay();
          ecranOLED.setCursor(0, 0);
          ecranOLED.setTextSize(1);
          ecranOLED.setTextColor(SSD1306_WHITE);
          ecranOLED.println(F("MODE CALIB"));
          ecranOLED.println(F(""));
          ecranOLED.println(F("Ne pas toucher"));
          ecranOLED.println(F("le capteur..."));
          ecranOLED.display();
          Calibration(); 
          ecranOLED.clearDisplay();
          ecranOLED.setCursor(0, 0);
          ecranOLED.println(F("CALIBRATION OK !"));
          ecranOLED.display();
          delay(3000);
          Menu = 0;
        }
        break;

      break;
    }
  }
}

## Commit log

2026-03-27 version 1 readme
    Added detailed project documentation including context, deliverables, required materials, and phases of engineering for a low-tech graphite sensor project.
2026-03-27 Revise README for analog conditioning and simulation details
    Updated the description of the analog conditioning section, including details about the LTC1050 op-amp and modifications to the feedback resistor. Enhanced the modeling and simulation section to clar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
2026-03-27 ajout photo
    Corrected text for clarity and coherence in the project description, specifically regarding the operation principle of the sensor and its engineering phases.
2026-03-27 photo
    Clarified the description of the amplifier circuit and added details about the filtering stages.
2026-04-11 ajout italique
    Updated the explanation of the sensor's operation to include variables in italics for clarity.
2026-04-11 Revise analysis and characterization in README
    Updated the analysis and characterization section with detailed explanations about the measurement device and results. Clarified the sensitivity factor and its implications for different pencil types.
2026-04-13 Update README to remove servo motor references
    Removed mention of the servo motor from the analysis and deliverables sections in the README.
2026-04-16 Revise README with system overview and analysis section
    Updated the README to include details about the mobile interface and measurement device.
2026-06-01 Add conclusion about sensor's functionality and use cases
    Added a conclusion section discussing the sensor's application and limitations.

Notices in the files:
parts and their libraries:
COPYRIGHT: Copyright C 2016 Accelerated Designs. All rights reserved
